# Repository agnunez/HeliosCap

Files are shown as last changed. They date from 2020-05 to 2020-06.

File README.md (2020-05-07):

# Welcome to HeliosCap!

This is a "poorman" **heliostat** (solar celostat) that allows tracking the Sun easily with a fix telescope optical tube aiming polar north. It use hard drives disk as a flat mirror (more discussion latter), and a couple of inexpensive stepper motors (28BYJ-48) plus an arduino-like MCU. 

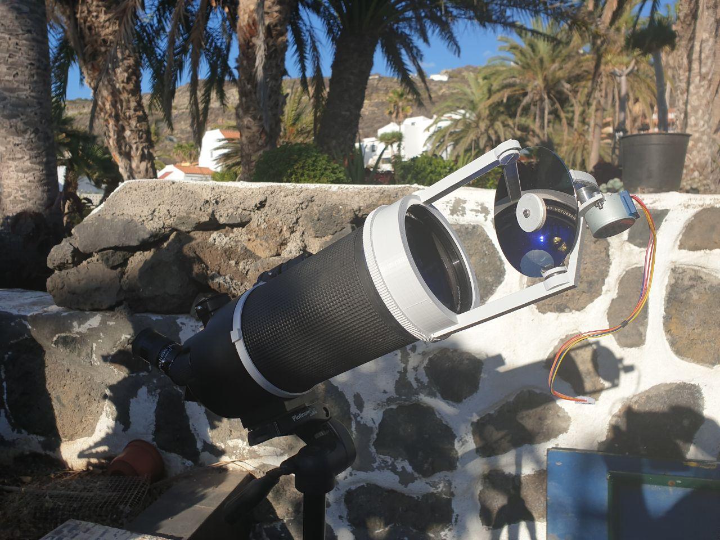
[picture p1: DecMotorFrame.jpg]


Test with Dec Motor frame only. RA motor still missing.

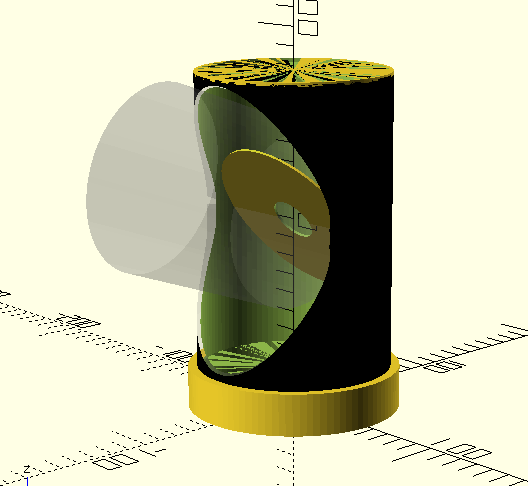
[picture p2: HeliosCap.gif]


Sun variying Dec during the year would require an elliptical mirror, but circular one is the only available option these days.

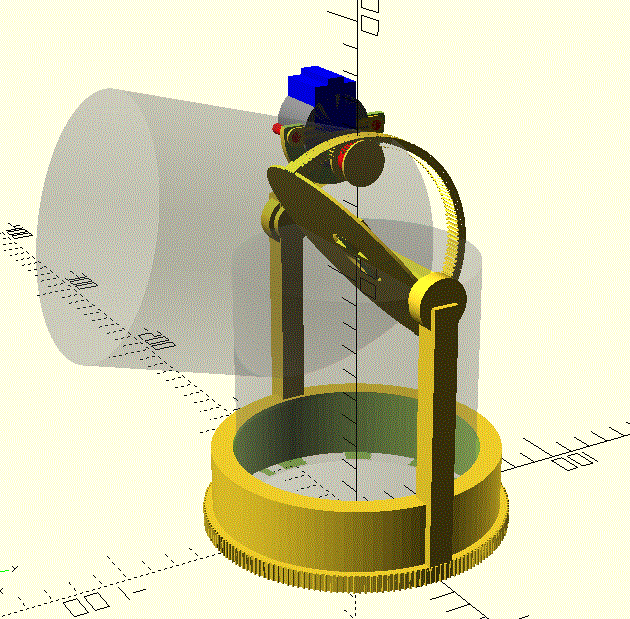
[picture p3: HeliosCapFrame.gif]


Inside a future tube, mirror will be steer to aim to any ecliptic objects, Moon and planets included.

It was designed during covid19 lock down in a small Atlantic island (La Palma), so no shopping was possible and only reuse of material available at home was feasible. I had a bunch of obsoletes 5" disk drives and knew that they are well polished, to avoid reading head crash so that was first choice to look for a flat mirror. Furthermore, even though their reflectivity is only around 60%, the Sun is really bright so the light lost after reflection even helps to reduce filters requirements and heat. In near future, hopeful when the lock down is over I hope to replace the mirror with a Newton Secondary elliptical one, and use a APO refractor lens to avoid central obstruction and obtain more contrast in resulting images.

The project is at testing phase, but the intention is to develop autonomous software to locate, track and even guide the Sun every day during the year, even in partially cloudy skies.

Leaving the optical tube fix and aligned to north (or south) pole will help in the second phase of the project, a bit more ambitious, that intend to build a DIY HelioSpectrograph. At least I have already the basic optical needs already available (scientific grid) adopting a Littrow configuration. to be continued... 

# Files

HeliosCap 3d parts have been designed with **OpenScad** in a parametric way, so one can adapt the sizes to its own telescope and flat mirror
# Software
A very simple soft will be provided using AccelStepper arduino library that allows HALFSTEP configuration for both RA and DEC motors. A second version, will use appropiate 3D printer like stepper driver and Nema motors for larger size version.

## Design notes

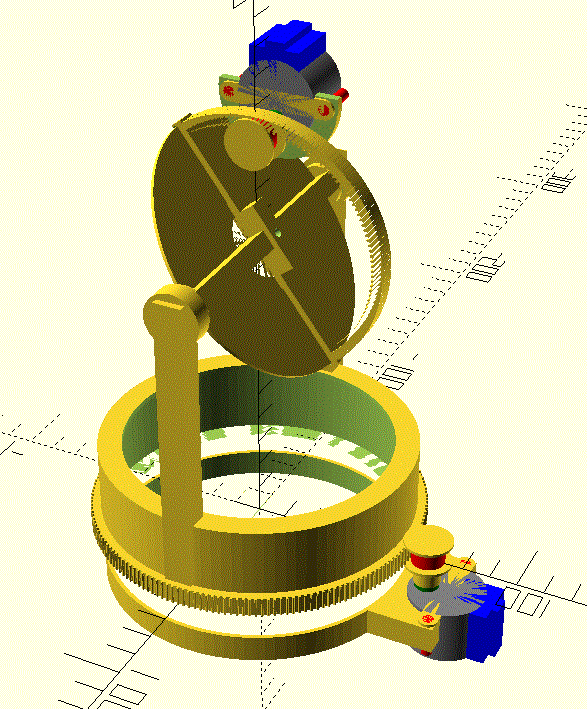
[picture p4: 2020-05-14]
HeliosCapRaDec.gif

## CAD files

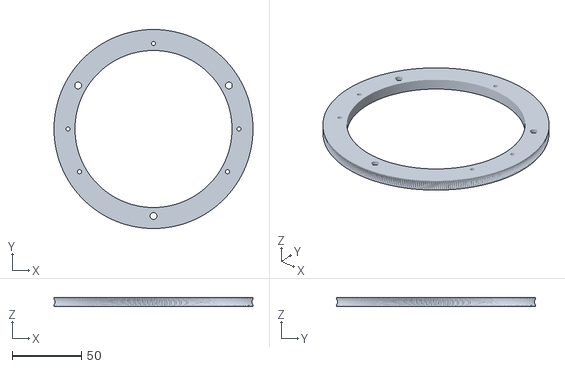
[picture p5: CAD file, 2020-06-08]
RA_gear_Thicker.stl
143.2 x 143.2 x 6.80

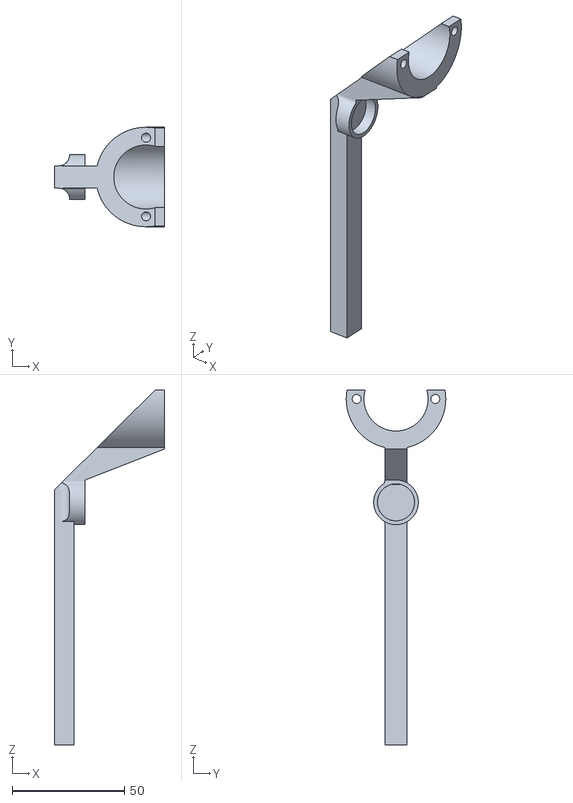
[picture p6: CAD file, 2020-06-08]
DecMotorArm.stl
49.0 x 44.3 x 158.0

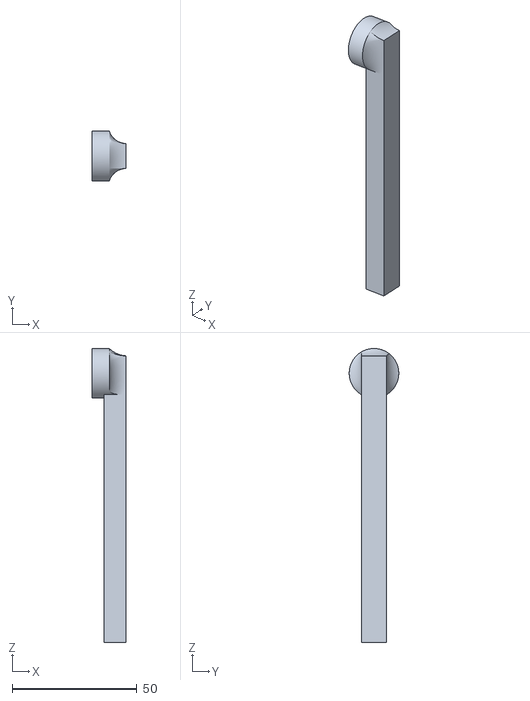
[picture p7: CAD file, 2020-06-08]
DecArm.stl
13.7 x 19.9 x 117.9

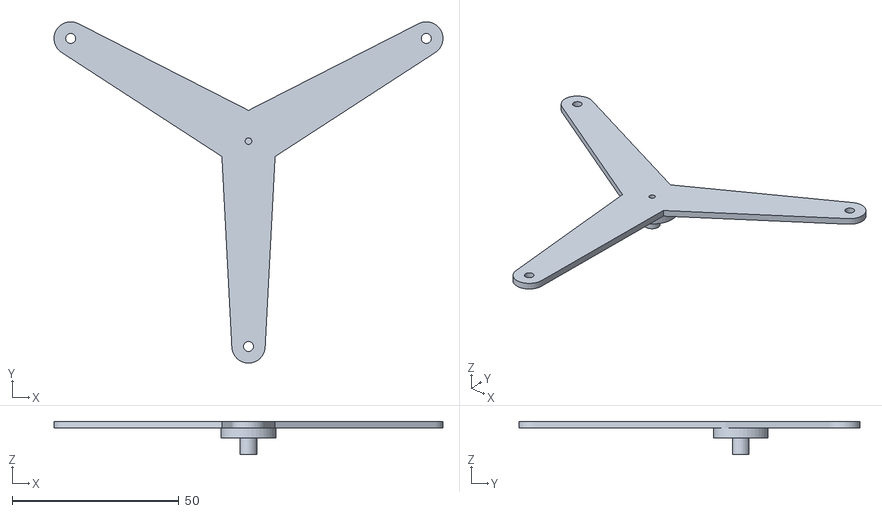
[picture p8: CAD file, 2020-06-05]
GearAdapter.stl
116.5 x 102.2 x 10.0

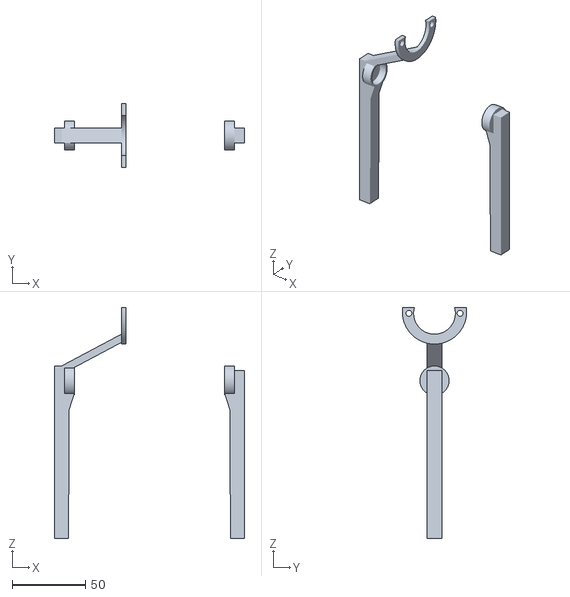
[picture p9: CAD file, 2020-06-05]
mirrorarms.stl
130.0 x 44.0 x 158.0

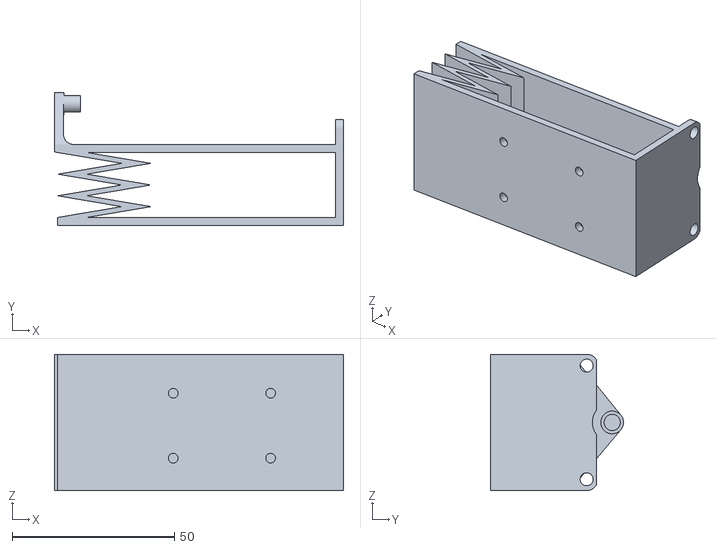
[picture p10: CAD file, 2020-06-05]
WormHolder.stl
89.0 x 41.0 x 42.0

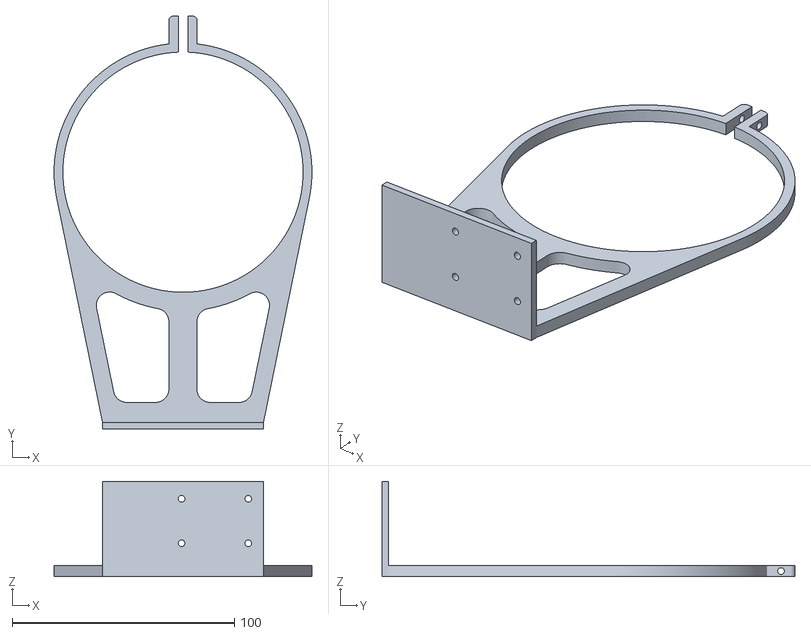
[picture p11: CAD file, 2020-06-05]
RAmotorTubeHolder.stl
116.0 x 185.7 x 42.8

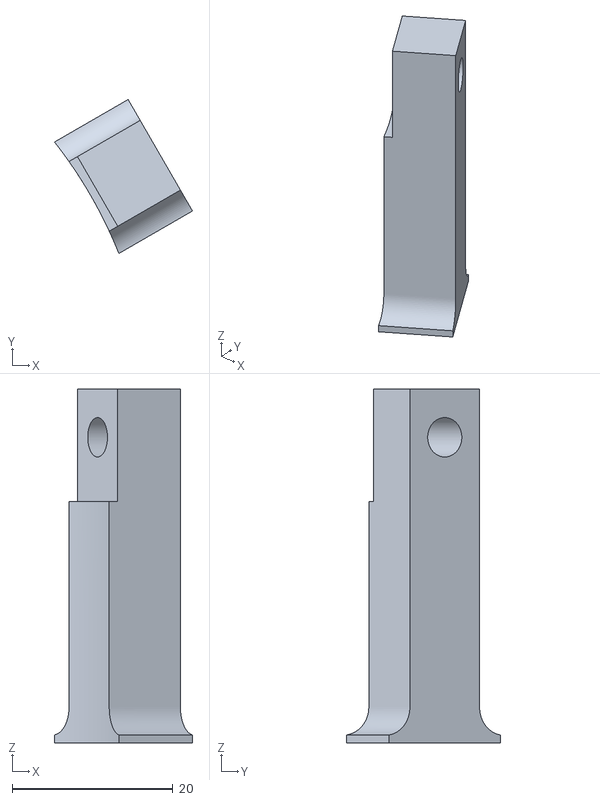
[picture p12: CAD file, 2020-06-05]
RAWheelHolder.stl
17.2 x 19.1 x 44.0

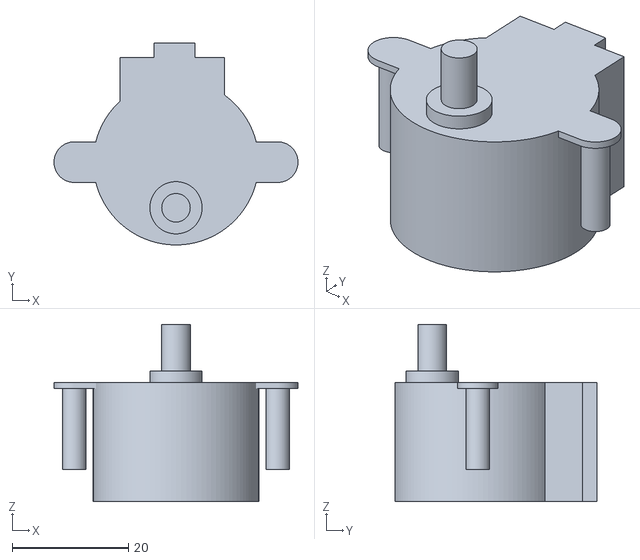
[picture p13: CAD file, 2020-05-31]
Motor.stl
42.0 x 34.8 x 30.5

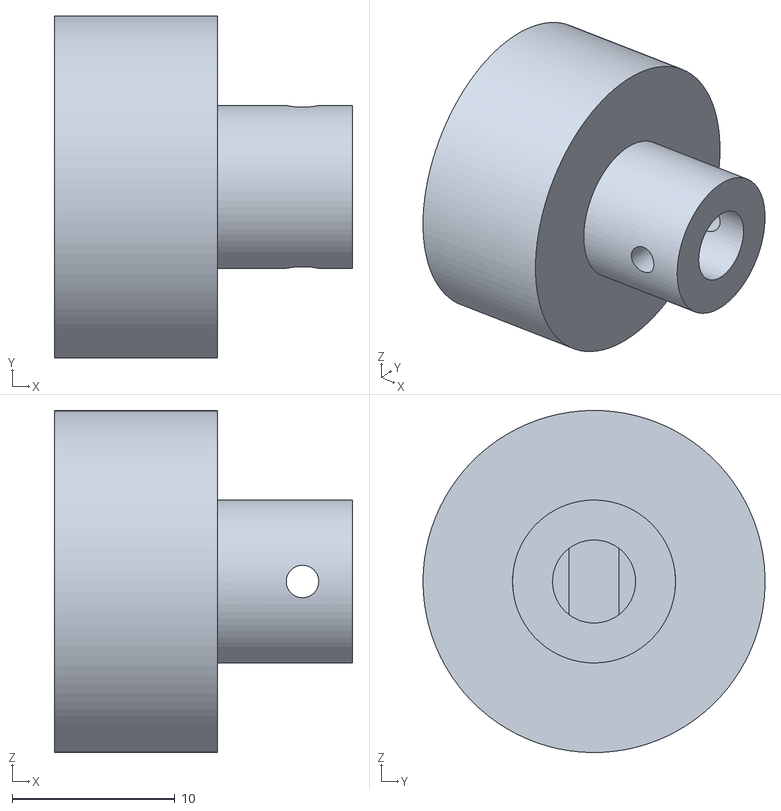
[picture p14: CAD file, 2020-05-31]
WormAdapter.stl
18.3 x 21.0 x 21.0

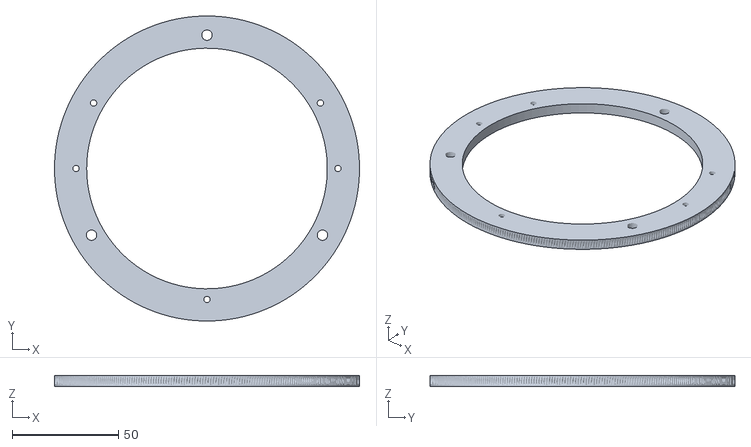
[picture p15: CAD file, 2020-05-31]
RA_gear.stl
143.2 x 143.2 x 5.00

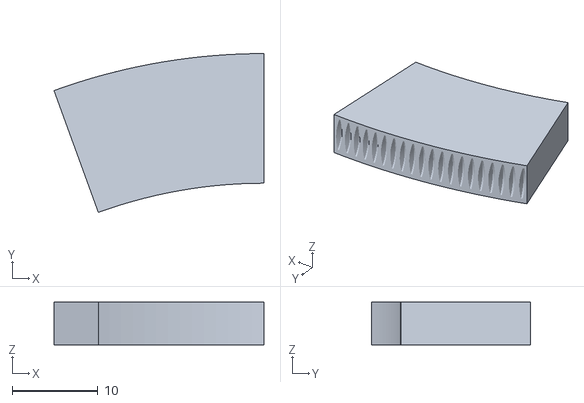
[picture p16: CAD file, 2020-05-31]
WormGearTestSector.stl
24.5 x 18.5 x 5.00

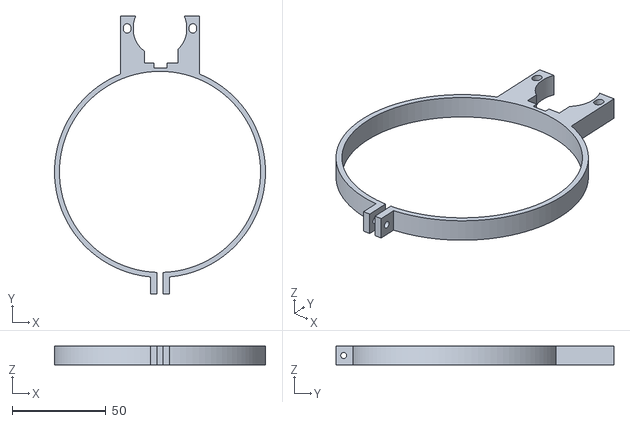
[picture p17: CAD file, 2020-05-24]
HeliosCapRaMotorHolder.stl
112.5 x 148.0 x 10.0

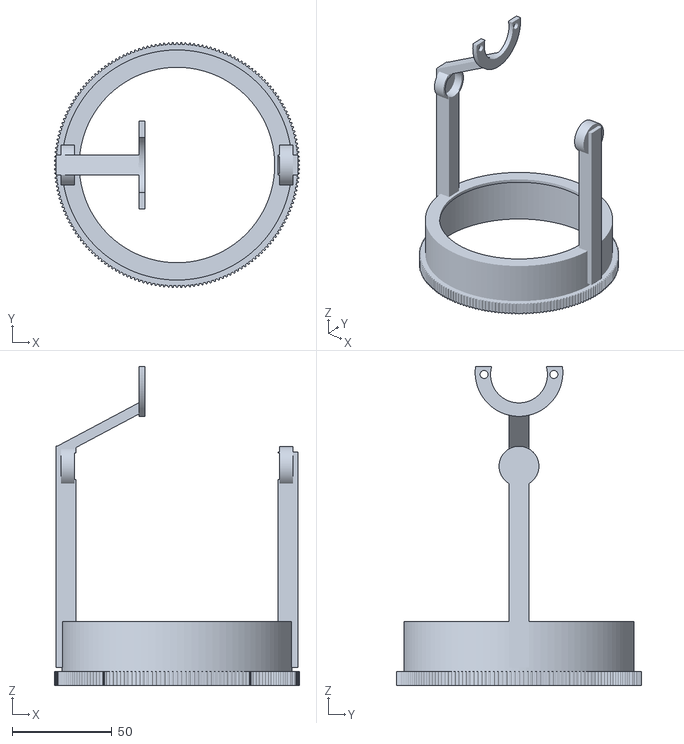
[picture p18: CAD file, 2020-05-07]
HeliosCap.stl
122.9 x 122.9 x 160.0

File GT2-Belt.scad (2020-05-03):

// N_teeth number of teeth
// belt_height  belt width
// bed extra belt thickness. 0 is no bed (standard)

// if dir>0 teeth outward, dir<0 teeth inward

//gt2_belt(N_teeth, belt_height, dir, bed);
//gt2_belt_arc(N_teeth, belt_height, dir, 180, bed);
  gt2_belt_arc(180, 7, 1, 180, 2);
//tooth(6,1, 0);  // single tooth outward
//tooth(6,-1, 0); // single tooth inward

module gt2_belt(N, bh, dir, bed){
    gt2_belt_arc(N, bh, dir, 360, bed);
}
module gt2_belt_arc(N, bh, dir, arc, bed) {
    linear_extrude(height=bh) {
        belt_radius = N / 3.14159;
        n = N * arc / 360;
        for (a =[0:arc/n:arc]) {
           rotate([0,0,a]) translate([-belt_radius,0]) tooth(bh,dir,bed);
        }
    }
}

module toothOut(bh,bed) {
        translate([-(2-.44/2+bed),0]) rotate(30) color("blue")circle(r=.44, $fn=6);
        translate([-(1.25+bed),-1.5]) color("red") square([1.25+bed,3]);
        translate([-(1.75+bed),-.44]) square([1.75+bed,.88]);
}
module toothIn(bh,bed) {
        translate([(2-.44/2+bed),0]) rotate(30) circle(r=.44, $fn=6);
        translate([0,-1.5]) color("red") square([1.25+bed,3]);
        translate([0,-.44]) square([1.75+bed,.88]);
}

module tooth(bh,dir,bed){
    if(dir>0) toothOut(bh,bed);
    if(dir<0) toothIn(bh,bed);
}

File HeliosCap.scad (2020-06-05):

/* HelioCap a celostat adapter as telescope cap for Solar observation */
/* (c) Agustin Nunez 2020  https://github.com/agnunez/HelioCap        */

use <GT2-Belt.scad>;
h1=30;         // height of cap adaptor ring
tod=110;       // telescope tube outer diameter. 
toh=35;        // telescope tube last cylinder height
d2=98.5;       // telescope original cap insercion diameter
w1=2;          // cap wall thickness
w2=2;          // mirror baffle thickness(black);
mod=95;        // flat mirror outer diameter.
mid=25;        // flat mirror inner diameter
a=sin(360*$t); // parameter for animation (-1..1)
dec=23.5*a;    // Ecliptic inclination 23º 27' 8" (47" less every 100y)
mt=1.26;       // mirror thickness
ma=45-dec/2;   // mirror angle
ms=80+h1;      // mirror spacing from telescope 
h2=ms+mod*0.6; // baffle height
bm=3.0;        // beam margin. free space around beam
bid=5;         // 625zz bearing inner diameter
bod=16;        // 625zz bearing outer diameter
bt=5;          // 625zz bearing thickness
brd=7.8;       // 625zz bearing rotating diameter
bw=7;          // GT2 belt width
dec_teeth=150; // GT2 teeth on DEC gear
ra_teeth=240; // GT2 teeth on RA gear
ra_d=2*ra_teeth/PI;   // ra diameter. l=ra_teeth*2 in GT2. l=2*PI*r  r=ra_teeth*2/(2PI)*2
wd1=15.25;
wd2=13;
wt1=5;
wt2=8.96;  // wheel thickness
wh=4.9;   // bearing hole diameter
wbd=10;   // bearing diameter
wht=3;    //wheel holder thickness
$fn=100;
bs=1.2;  // bearing scale to allocate hollow room in cap for play 

//// execution
//mirror();
//***mirror_holder();  // uncomment to generate mirror holder stl
//***mirror_gear();    // uncomment to generate mirror gear stl
//***mirror_shaft();   // uncomment to generate mirror central  piece
//bearing_caps();
//***mirror_retainer();
//fake_bearing();
//**translate([0,0,ms])rotate([-ma,0,0])mirror_assembly(); // flat 1st surface mirror
//motor();
//translate([-35.3,0,ms+46])rotate([-90,180,-90])motor(); // dec motor
//translate ([0,0,ms]) beam();  // beam toward telescope lense
//translate ([0,0,ms]) rotate([-ma*2,0,0]) beam(); // beam toward Sun
//pulley20();  
//translate([0,tod/2+16,-32])motor(); // ra motor
//translate([0,0,h1])telescope();  //*** uncomment to draw OTA
//ra_bearing(1,a=1);
cap_frame();           //*** uncomment to generate cap_frame main gear stl
//ra_motor_holder();     //*** uncoment to generat RA motor holder stl
//echo((tod+wd1)/2);
//mirrorarms();

module ra_bearing(s,a){ 
   translate([0,0,wht])union(){
    rotate([0,0, 30])translate([(tod+wd1)/2,0,0])vslot_wheel(s,a);
    rotate([0,0,150])translate([(tod+wd1)/2,0,0])vslot_wheel(s,a);
    rotate([0,0,270])translate([(tod+wd1)/2,0,0])vslot_wheel(s,a);
  }
  translate([0,tod/2-w2,toh+w1+0.4])rotate([90,0,0])translate([0,0,-wt2/2])vslot_wheel(s,a);
  rotate([0,0,120])translate([0,tod/2-w2,toh+w1+0.4])rotate([90,0,0])translate([0,0,-wt2/2])vslot_wheel(s,a);
  rotate([0,0,-120])translate([0,tod/2-w2,toh+w1+0.4])rotate([90,0,0])translate([0,0,-wt2/2])vslot_wheel(s,a);
}
module vslot_wheel(s,a){
 scale([s,s,s])
 difference(){
  union(){
    color("black")cylinder(h=(wt2-wt1)/2-0.2,d2=wd1,d1=wd2);
    color("black")translate([0,0,(wt2-wt1)/2])cylinder(h=wt1,d=wd1);
    color("black")translate([0,0,(wt2-wt1)/2+wt1])cylinder(h=(wt2-wt1)/2-0.2,d1=wd1,d2=wd2);
    color("gray")translate([0,0,-0.1])cylinder(h=wt2,d=wbd);
  }
  translate([0,0,-1])cylinder(h=wt2+2,d=wh);
  
 }
 if(a==1){color("red")translate([0,0,-10])cylinder(h=wt2+20,d=wh);}
}

module telescope(){
    translate([0,0,-toh/2]) union(){
     color("gray")difference(){
      cylinder(h=toh,d=tod,center=true,$fn=100);
      cylinder(h=toh+1,d=d2,center=true,$fn=100);
     }
     translate([0,0,-(toh+8.5)/2])color("black")cylinder(h=8.5,d=tod-2,center=true,$fn=100);
     color("gray")translate([0,0,-8.5-(toh+140)/2])cylinder(h=140,d=tod-1,center=true,$fn=100);
   }
}

module ra_motor_holder(){
  translate([0,0,-18]) difference(){
    union(){
      cylinder(h=10,d=tod+2.5,center=true,$fn=100);
      translate([-21,tod/2-5,-5])cube([42,27+6,10]);
      rotate([0,0,180])translate([-5,tod/2-5,-5])cube([10,15,10]);
      translate([0,50,0])rotate([0,90,0])cylinder(h=20,d=3,center=true,$fn=100);  
    }    
    cylinder(h=10+1,d=tod-4+1.2,center=true,$fn=100);
    rotate([0,0,180])translate([-1.5,tod/2-5-2,-7])cube([3,20,20]);
    translate([0,tod/2+16+5,-14])rotate([0,0,180])motor();
    translate([0,tod/2+16+6,-14])rotate([0,0,180])motor();
    translate([0,-tod/2-6,0])rotate([0,90,0])cylinder(h=20,d=3.2,center=true,$fn=100);  
  }
  //uncoment to draw RA motor in place
  //translate([0,0,-18]) translate([0,tod/2+16+7,-14])rotate([0,0,180])motor();
}
module dec_motor_holder(){
difference(){
  union(){
    translate([-60.9,-5,ms+9.6])rotate([0,62,0])translate([0,0,1])cube([5,10,100]);
    translate([-17.5,0,ms+47])rotate([0,90,0])cylinder(h=3,d=44,center=true,$fn=100);
      
  }
 translate([-20.9,-24,ms+50])cube([5,50,21]);
 translate([-35.3,0,ms+46])rotate([-90,180,-90])motor();
 translate([-17.5,0,ms+47])rotate([0,90,0])translate([0,0,26.5])cylinder(h=50,d=44,center=true,$fn=100);
 translate([0,0,ms])rotate([0,90,0])cylinder(h=mod+bt+bm+10,d=bod+0.5,center=true,$fn=100); 
}
  //translate([-35.3,0,ms+46])rotate([-90,180,-90])motor();
}

module mirrorarms(){
  //dec_motor_holder();
  //gt2_belt_arc(ra_teeth,bw, 1, 360, 2);
  difference(){
    union(){
      difference(){ // cap ring
        union(){
          s=7; // enlargment fix
          translate([tod/2,-5,bw+2-s])cube([10,10,ms-2+s]);
          translate([ tod/2   ,-5,ms-20])rotate([0,-18,0])cube([10,10,12]);
          translate([-tod/2-10,-5,bw+2-s])cube([10,10,ms+8-bw+s]);
          translate([-tod/2,-5,ms-20])rotate([0,18,0])translate([-10,0,0])cube([10,10,12]);
        }
        translate([0,0,h1/2])cylinder(h=h1+4.5,d=tod+1.5,center=true,$fn=100);
        translate([0,0,h1/2])cylinder(h=h1+20,d=mod+bm+0.5,center=true,$fn=100);
        ra_bearing(1,a=1);
        ra_bearing(bs,a=0);
      }  
      translate([0,0,ms])rotate([-ma,0,0]) 
      union(){
        translate([mod/2+0.5,0,0])rotate([0,90,0]) bearing_caps();  // dec bearing holders
        translate([-mod/2-0.5,0,0])rotate([0,-90,0]) bearing_caps();   
      }
    }
    translate([0,0,ms])rotate([0,90,0])                       // dec bearing axis 
    cylinder(h=mod+bt+bm+10,d=bod+0.5,center=true,$fn=100);
    //ra_bearing(1,a=1);
  }

#difference(){
  union(){
    translate([-60.9,-5,ms+9.6])rotate([0,62,0])translate([0,0,1])cube([5,10,100]);
    translate([-17.5,0,ms+47])rotate([0,90,0])cylinder(h=3,d=44,center=true,$fn=100);
      
  }
 translate([-20.9,-24,ms+50])cube([5,50,21]);
 translate([-35.3,0,ms+46])rotate([-90,180,-90])motor();
 translate([-17.5,0,ms+47])rotate([0,90,0])translate([0,0,26.5])cylinder(h=50,d=44,center=true,$fn=100);
 translate([0,0,ms])rotate([0,90,0])cylinder(h=mod+bt+bm+10,d=bod+0.5,center=true,$fn=100); 
}
  //translate([-35.3,0,ms+46])rotate([-90,180,-90])motor();

}    

module cap_frame(){
  dec_motor_holder();
  gt2_belt_arc(ra_teeth,bw, 1, 360, 2);
  difference(){
    union(){
      difference(){ // cap ring
        union(){
          translate([0,0,(h1+w1)/2])cylinder(h=h1+w1,d=tod+w1*2+0.5,center=true,$fn=100);
          s=7; // enlargment fix
          translate([tod/2,-5,bw+2-s])cube([10,10,ms-2+s]);
          translate([ tod/2   ,-5,ms-20])rotate([0,-18,0])cube([10,10,12]);
          translate([-tod/2-10,-5,bw+2-s])cube([10,10,ms+8-bw+s]);
          translate([-tod/2,-5,ms-20])rotate([0,18,0])translate([-10,0,0])cube([10,10,12]);
          rotate([0,0,-30])translate([tod/2,-5,bw+2-s])cube([11,10,41]);
          rotate([0,0,90])translate([tod/2,-5,bw+2-s])cube([11,10,41]);
          rotate([0,0,210])translate([tod/2,-5,bw+2-s])cube([11,10,41]);
          difference(){   //  hollow plate holding RA gear
            cylinder(h=wht,d=ra_d+1);
            for (i = [0:30:360]) { 
              rotate([0,0,i+15])translate([0,ra_d/2-(ra_d-tod)/4,0])
                translate([0,0,-1])cylinder(h=wht+2,d=(ra_d-tod)/2);
            }
            translate([0,0,-1])cylinder(h=wht+2,d=tod+1);
          }
        }
        translate([0,0,h1/2])cylinder(h=h1+4.5,d=tod+1.5,center=true,$fn=100);
        translate([0,0,h1/2])cylinder(h=h1+20,d=mod+bm+0.5,center=true,$fn=100);
        ra_bearing(1,a=1);
        ra_bearing(bs,a=0);
      }  
      translate([0,0,ms])rotate([-ma,0,0]) 
      union(){
        translate([mod/2+0.5,0,0])rotate([0,90,0]) bearing_caps();  // dec bearing holders
        translate([-mod/2-0.5,0,0])rotate([0,-90,0]) bearing_caps();   
      }
    }
    translate([0,0,ms])rotate([0,90,0])             // dec bearing axis 
    cylinder(h=mod+bt+bm+10,d=bod+0.5,center=true,$fn=100);
    //ra_bearing(1,a=1);
  }
}
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

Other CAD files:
TestCap.stl
MotorHolder.stl
MirrorGear.stl
MirrorHolder.stl
BearingCap.stl
BoltAdapter.stl
GT2-arc-test.stl
MirrorRetainer.stl
MirrorShaft.stl

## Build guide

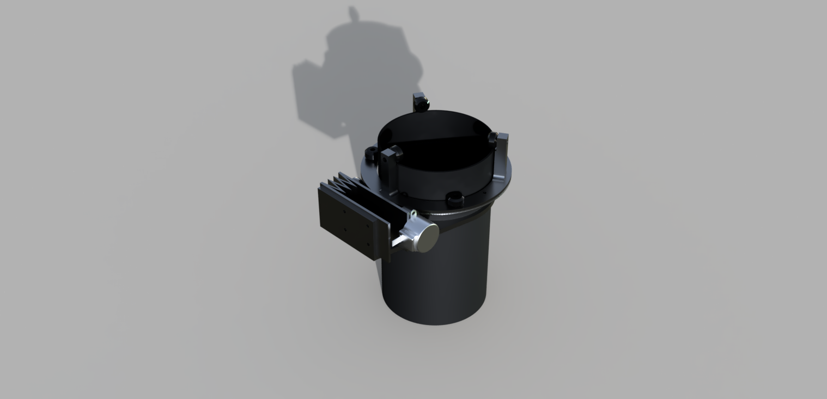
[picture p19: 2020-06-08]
RA_Assembly.png

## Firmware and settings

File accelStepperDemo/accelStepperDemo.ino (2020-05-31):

// Bounce.pde
// -*- mode: C++ -*-
//
// Make a single stepper bounce from one limit to another
//
// Copyright (C) 2012 Mike McCauley
// $Id: Random.pde,v 1.1 2011/01/05 01:51:01 mikem Exp mikem $
#include <AccelStepper.h>
#include <ESP8266WiFi.h>


int delayValue = 0;
int maxdelay = 200;
// Define a stepper and the pins it will use
AccelStepper stepper(AccelStepper::HALF4WIRE, D2,D0,D1,D3); // Defaults to AccelStepper::FULL4WIRE (4 pins) on 2, 3, 4, 5
void setup()
{  
  WiFi.mode(WIFI_OFF); 
  // Change these to suit your stepper if you want
  stepper.setMaxSpeed(5000);
  //stepper.setAcceleration(20);
  //stepper.moveTo(500);
  Serial.begin(9600);
}
void loop()
{
   //handleSerial();
   stepper.move(1);
   stepper.runToPosition();
   delay(1766.5);
   //delay(delayValue);
}

void handleSerial() {
 while (Serial.available() > 0) {
   char incomingCharacter = Serial.read();
   Serial.println(delayValue);
   switch (incomingCharacter) {
     case '0':
      delayValue = 0;
      if (delayValue >= maxdelay)
         delayValue = maxdelay;
      break;
     case '-':
      delayValue = delayValue - 100;
      if (delayValue >= maxdelay)
         delayValue = maxdelay;
      break;
     case '+':
      delayValue = delayValue + 100;
      if (delayValue <= 0)
         delayValue = 0;
      break;
    }
 }
}

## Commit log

2020-05-02 HeliosCap mirror case celostat for Solar observation with fix telescope. Inital commit
    [HeliosCap.scad]
2020-05-02 New shaft and mirror holder
    [HeliosCap.scad, MirrorHolder.stl, MirrorShaft.stl]
2020-05-02 mirror shaft and holder added
    [HeliosCap.scad, MirrorHolder.stl, MirrorRetainer.stl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]
2020-05-03 mirror assembly, included GT2 gear, completed
    [GT2-Belt.scad, GT2-arc-test.stl, HeliosCap.scad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]
2020-05-04 cap_frame 1st version
    [BearingCap.stl, HeliosCap.scad, MirrorGear.stl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]
2020-05-05 Dec motor integrated
    [HeliosCap.scad, MirrorGear.stl, MotorHolder.stl]
2020-05-06 increasd cap height and width and correct ms bug
    [GearCalculations.xlsx, HeliosCap.scad, Libro1.xlsx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]
2020-05-06 Added README 2nd image Frame
2020-05-07 v0.9 HeliosCap. missing RA motor only
    [GearCalculations.xlsx, HeliosCap.scad, HeliosCap.stl]
2020-05-14 new RA v0.1
    [HeliosCap.scad, HeliosCapRaMotorHolder.stl]
2020-05-22 v1.01 RA gear and wheels mimic
    [HeliosCap.scad]
2020-05-22 v1.02 parameterized wheels hollows
    [HeliosCap.scad]
2020-05-22 v1.05 cap_frame with ra bearing rc1
    [HeliosCap.scad]
2020-05-23 v1.06 cap_frame with ra bearing rc1 with stl and gcode
2020-05-24 v1.07 cap_frame simplified to achieve NO SUPPORTS
    [HeliosCap.scad, HeliosCapRaMotorHolder.stl]
2020-05-25 v1.1 cap_frame simplified to achieve print with NO SUPPORTS
    [HeliosCap.scad]
2020-05-31 v1.8 with new worm gear
    [Motor.stl, RA_gear.stl, WormAdapter.stl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]
2020-06-05 New worm design in F360
    [BoltAdapter.stl, GearAdapter.stl, HeliosCap.scad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]
2020-06-08 v1.01 second iteration with worm gear
    [DecArm.stl, DecMotorArm.stl, RA_gear_Thicker.stl]
